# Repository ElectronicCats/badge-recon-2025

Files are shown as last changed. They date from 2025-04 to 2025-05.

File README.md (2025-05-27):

# REcon Badge 2025

This is the official repository of the REcon Badge 2025. Here you will find the source code for the badge, as well as the documentation and instructions to build it.

## Getting Started

Your badge comes with a pre-installed firmware, but in case you want to reprogram it, you can follow these steps:

1. Download the latest `firmware.uf2` file from the [releases](https://github.com/ElectronicCats/badge-recon-2025/releases/latest) page.

2. Connect the badge to your computer using a USB-C cable.

3. Press and hold the button on the badge while connecting it to the USB port. This will put the badge in bootloader mode.

4. Once the badge is connected, it will appear as a USB drive named `RPI-RP2`. Copy the `firmware.uf2` file to the root of the drive.

5. After copying the file, the badge will automatically reboot and start running the new firmware.

> **Note:** Sometimes you may need to press the reset button on the badge after copying the firmware file to ensure it starts correctly.

### Building the Firmware

To build the firmware from source, you will need to have [Docker](https://www.docker.com/) installed on your machine. Once you have Docker set up, you can follow these steps:

1. Clone the repository:

Using HTTPS:

```bash
git clone https://github.com/ElectronicCats/badge-recon-2025.git
```

Using SSH:

```bash
git clone git@github.com:ElectronicCats/badge-recon-2025.git
```

2. Navigate to the firmware directory:

```bash
cd badge-recon-2025/firmware
```

3. Build the firmware using Docker:

```bash
./build.sh
```

This script will create a `firmware.ino.uf2` file in the `firmware/build` directory.

> To flash the firmware to the badge, follow the same steps as mentioned in the "Getting Started" section, but use the newly built `firmware.ino.uf2` file instead of the pre-built one.

> If you find any issues, please open an issue on the GitHub repository.

## User guide

Your badge comes with an SSD1306 OLED display and 4 buttons for navigation. When you power on the badge, it will display a welcome screen and then show the main menu after you press any button.

All the available applications are listed in the following diagram:

```mermaid
flowchart TD
    Start([Power On]) --> Init[Initialize Hardware]
    Init --> Welcome[Welcome Screen]
    Welcome --> MainMenu[Main Menu]
    
    MainMenu --> Apps[Apps]
    MainMenu --> About[About Screen]
    
    Apps --> NFCMenu[NFC Menu]
    Apps --> MagspoofMenu[Magspoof Menu]
    
    %% NFC Menu items
    NFCMenu --> DetectTags[Detect Tags]
    NFCMenu --> DetectReaders[Detect Readers]
    NFCMenu --> ReadBlock[Read Block]
    NFCMenu --> WriteBlock[Write Block]
    
    %% Magspoof Menu items
    MagspoofMenu --> Emulate[Emulate]
    MagspoofMenu --> Setup[Setup]
    MagspoofMenu --> Help[Help]
    
    %% NFC operations
    DetectTags --> SetReaderMode[Set Reader Mode]
    SetReaderMode --> TagDetection{Tag Detected?}
    TagDetection -->|Yes| DisplayTagInfo[Display Tag Info]
    TagDetection -->|No| BackPressed{Back Pressed?}
    BackPressed -->|Yes| NFCMenu
    BackPressed -->|No| TagDetection
    DisplayTagInfo --> WaitForRemoval[Wait For Tag Removal]
    WaitForRemoval --> BackToMenu[Wait For Back Button]
    BackToMenu --> NFCMenu
    
    %% Magspoof operations
    Setup --> SerialPrompt[Serial Prompt for Tracks]
    SerialPrompt --> InputTracks[Input Track Data]
    InputTracks --> TracksUpdated[Tracks Updated]
    TracksUpdated --> MagspoofMenu
    
    %% Input controller
    subgraph InputControl [Input Controller]
        UpButton[Up Button]
        DownButton[Down Button]
        SelectButton[Select Button]
        BackButton[Back Button]
    end
    
    %% Easter egg
    UpButton --> KonamiCheck{Konami Code?}
    KonamiCheck -->|Yes| EasterEgg[Easter Egg hint]
    KonamiCheck -->|No| MainMenu
```

### NFC Applications

- **Read Block** and **Write Block** applications are the same as **Detect Tags**, but they perform read and read/write operations if the detected tag is a Mifare Classic tag.
- **Detect Readers** allows you to detect NFC readers by emulating a tag.

### Magspoof Application

The **Magspoof** application allows you to emulate a magnetic stripe card.

- You can set up the tracks by entering the data through the serial prompt, use 9600 baud rate to communicate with the badge.
- The **Emulate** option allows you to emulate the magnetic stripe card with the configured tracks.

### Easter Egg

You can get a hint about the Easter egg by pressing the Konami code while the badge shows the REcon logo. The Konami code is:

```
Up, Up, Down, Down, Left, Right, Left, Right
```

## License

<a href="https://github.com/ElectronicCats">
    
</a>

Electronic Cats invests time and resources providing this open source design, please support Electronic Cats and open-source hardware by purchasing products from Electronic Cats!

Designed by Electronic Cats.

Firmware released under an GNU AGPL v3.0 license. See the LICENSE file for more information.

Hardware released under an CERN Open Hardware Licence v1.2. See the LICENSE_HARDWARE file for more information.

Electronic Cats is a registered trademark, please do not use if you sell these PCBs.

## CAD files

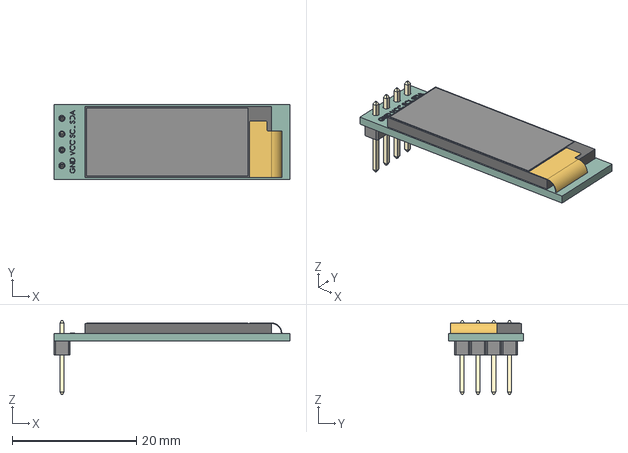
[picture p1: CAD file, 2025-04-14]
hardware/Footprints/3d/128x32-OLED.STEP
38.0 x 12.0 x 11.9 mm

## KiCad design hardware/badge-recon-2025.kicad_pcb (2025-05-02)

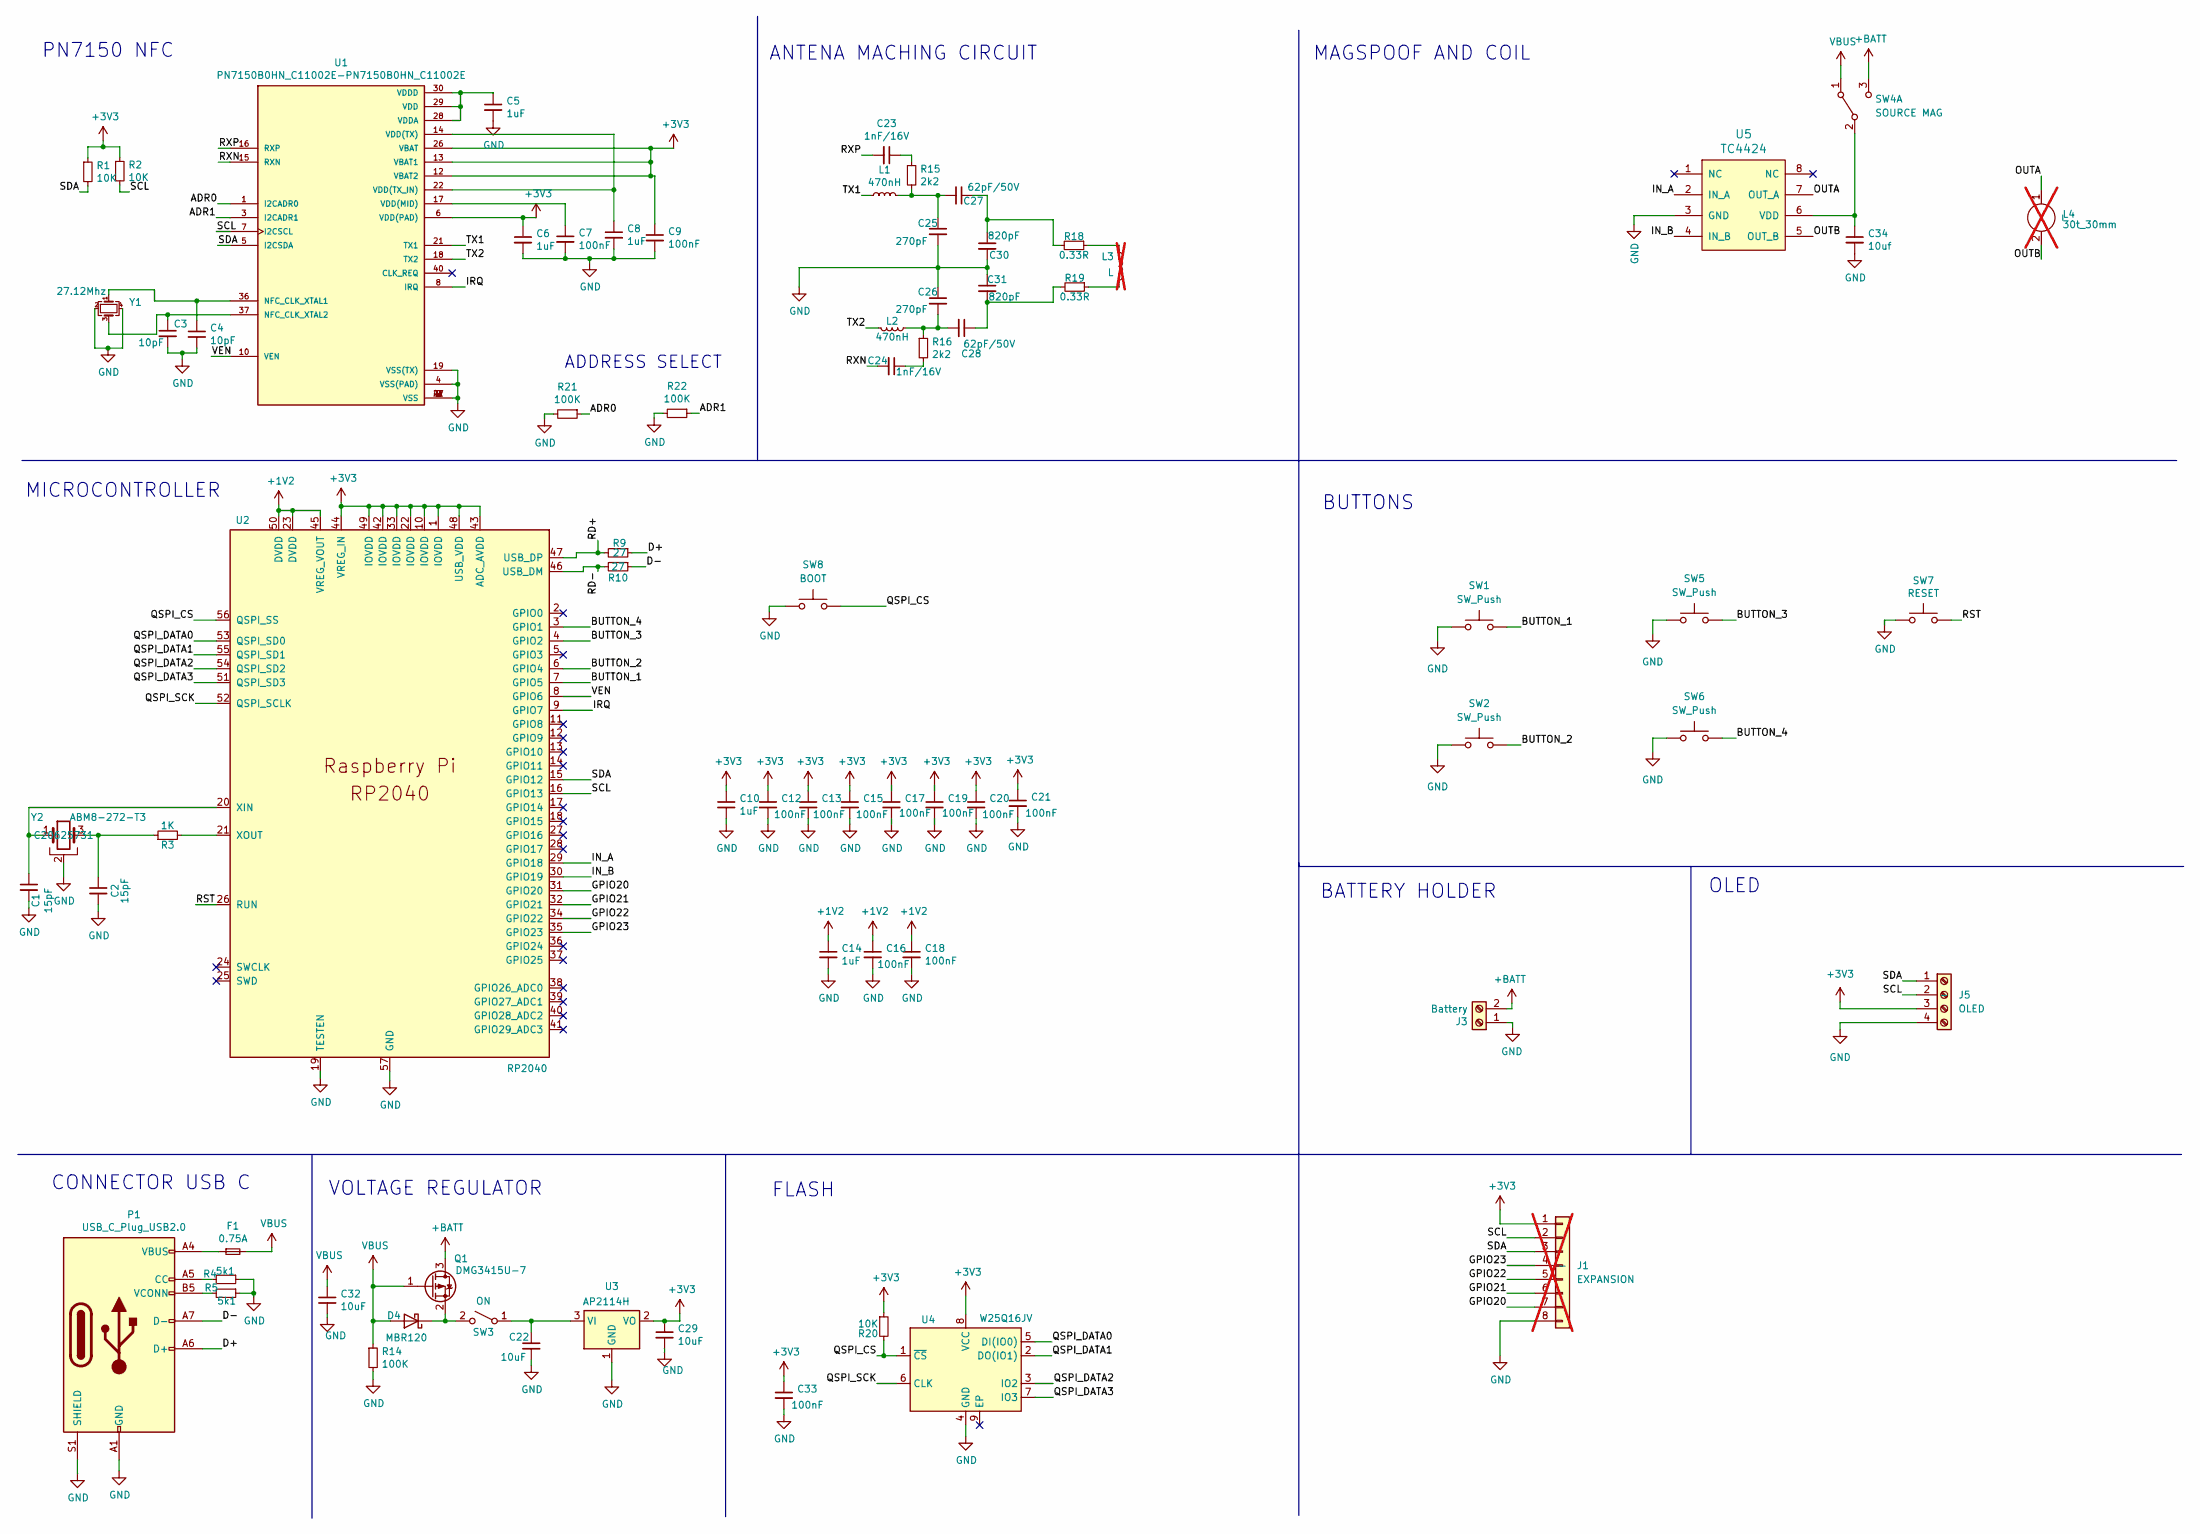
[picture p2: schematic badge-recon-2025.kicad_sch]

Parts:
C1, C2: 15pF; C_0603_1608Metric; LCSC# C1644
C3, C4: 10pF; C_0603_1608Metric; LCSC# C106245
C5, C6, C8, C10, C14: 1uF; C_0603_1608Metric; LCSC# C15849
C7, C9, C12, C13, C15, C16, C17, C18, C19, C20, C21, C33: 100nF; C_0603_1608Metric; LCSC# C282519
C22, C29, C32: 10uF; C_0603_1608Metric; LCSC# C85713
C23, C24: 1nF/16V; C_0603_1608Metric; LCSC# C519507
C25, C26: 270pF; C_0603_1608Metric; LCSC# C107046
C27, C28: 62pF/50V; C_0603_1608Metric; LCSC# C282073
C30, C31: 820pF; C_0603_1608Metric; LCSC# C107057
C34: 10uf; C_0603_1608Metric; LCSC# C96446
D4: MBR120; D_SOD-123F; LCSC# C130880
F1: 0.75A; Fuse_1812_4532Metric; LCSC# C3107
J1: EXPANSION; PinHeader_1x08_P2.54mm_Vertical; not fitted
J3: Battery; BAT-TH_BH-AAA-A1AJ024; LCSC# C5290193
J5: OLED; Display OLED 128 x32
L1, L2: 470nH; L_0603_1608Metric_Pad1.05x0.95mm_HandSolder; LCSC# C2044483
L3: L; NFC_Antenna_4T_Crossover_Final; not fitted
L4: 30t_30mm; Coil_30t_30mm_0.2_0.2_0.6_0.3; not fitted
P1: USB_C_Plug_USB2.0; C393939; LCSC# C393939
Q1: DMG3415U-7; SOT-23; LCSC# C96616
R1, R2, R20: 10K; R_0603_1608Metric; LCSC# C2930027
R3: 1K; R_0603_1608Metric; LCSC# C112433
R4, R5: 5k1; R_0603_1608Metric; LCSC# C23186
R9, R10: 27; R_0603_1608Metric; LCSC# C403464
R14, R21, R22: 100K; R_0603_1608Metric; LCSC# C15458
R15, R16: 2k2; R_0603_1608Metric; LCSC# C113303
R18, R19: 0.33R; R_0603_1608Metric; LCSC# C2934252
SW1, SW2, SW5, SW6: SW_Push; SW_SPST_TL3342; LCSC# C318889
SW3: ON; MSK12C02; LCSC# C431540
SW4: SOURCE MAG; JS202011CQN; LCSC# C5149820
SW7: RESET; SW_SPST_TL3342; LCSC# C318889
SW8: BOOT; SW_SPST_TL3342; LCSC# C318889
U1: PN7150B0HN_C11002E-PN7150B0HN_C11002E; QFN-40-1EP_6x6mm_P0.5mm_EP4.6x4.6mm; LCSC# C702907
U2: RP2040; RP2040-QFN-56; LCSC# C2040
U3: AP2114H; SOT-223-3_TabPin2; LCSC# C150716
U4: W25Q16JV; SOIC-8_5.3x5.3mm_P1.27mm; LCSC# C82317
U5: TC4424; SOIC-8_3.9x4.9mm_P1.27mm; LCSC# C7498963
Y1: 27.12Mhz; Crystal_SMD_2016-4Pin_2.0x1.6mm; LCSC# C338245
Y2: ABM8-272-T3; Crystal_SMD_Abracon_ABM8G-4Pin_3.2x2.5mm; LCSC# C20625731

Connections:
+1V2: C14.1, C16.1, C18.1, U2.23 (DVDD), U2.45 (VREG_VOUT), U2.50 (DVDD)
+3V3: C6.1, C9.1, C10.1, C12.1, C13.1, C15.1, C17.1, C19.1, C20.1, C21.1, C29.1, C33.1, J1.1, J5.3, R1.1, R2.1, R20.1, U1.6 (VDD(PAD)), U1.12 (VBAT2), U1.13 (VBAT1), U1.26 (VBAT), U2.1 (IOVDD), U2.10 (IOVDD), U2.22 (IOVDD), U2.33 (IOVDD), U2.42 (IOVDD), U2.43 (ADC_AVDD), U2.44 (VREG_IN), U2.48 (USB_VDD), U2.49 (IOVDD), U3.2 (VO), U4.8 (VCC)
+BATT: J3.2, Q1.3 (D), SW4.3 (C)
/ADR0: R21.1, U1.1 (I2CADR0)
/ADR1: R22.1, U1.3 (I2CADR1)
/BUTTON_1: SW1.2, U2.7 (GPIO5)
/BUTTON_2: SW2.2, U2.6 (GPIO4)
/BUTTON_3: SW5.2, U2.4 (GPIO2)
/BUTTON_4: SW6.2, U2.3 (GPIO1)
/D+: P1.A6 (D+), R9.1
/D-: P1.A7 (D-), R10.1
/GPIO20: J1.7, U2.31 (GPIO20)
/GPIO21: J1.6, U2.32 (GPIO21)
/GPIO22: J1.5, U2.34 (GPIO22)
/GPIO23: J1.4, U2.35 (GPIO23)
/IN_A: U2.29 (GPIO18), U5.2 (IN_A)
/IN_B: U2.30 (GPIO19), U5.4 (IN_B)
/IRQ: U1.8 (IRQ), U2.9 (GPIO7)
/OUTA: L4.1, U5.7 (OUT_A)
/OUTB: L4.2, U5.5 (OUT_B)
/QSPI_CS: R20.2, SW8.2, U2.56 (QSPI_SS), U4.1 (~CS)
/QSPI_DATA0: U2.53 (QSPI_SD0), U4.5 (DI(IO0))
/QSPI_DATA1: U2.55 (QSPI_SD1), U4.2 (DO(IO1))
/QSPI_DATA2: U2.54 (QSPI_SD2), U4.3 (IO2)
/QSPI_DATA3: U2.51 (QSPI_SD3), U4.7 (IO3)
/QSPI_SCK: U2.52 (QSPI_SCLK), U4.6 (CLK)
/RD+: R9.2, U2.47 (USB_DP)
/RD-: R10.2, U2.46 (USB_DM)
/RST: SW7.2, U2.26 (RUN)
/RXN: C24.2, U1.15 (RXN)
/RXP: C23.2, U1.16 (RXP)
/SCL: J1.2, J5.2, R2.2, U1.7 (I2CSCL), U2.16 (GPIO13)
/SDA: J1.3, J5.1, R1.2, U1.5 (I2CSDA), U2.15 (GPIO12)
/TX1: L1.1, U1.21 (TX1)
/TX2: L2.2, U1.18 (TX2)
/VEN: U1.10 (VEN), U2.8 (GPIO6)
GND: C1.2, C2.2, C3.2, C4.2, C5.2, C6.2, C7.2, C8.2, C9.2, C10.2, C12.2, C13.2, C14.2, C15.2, C16.2, C17.2, C18.2, C19.2, C20.2, C21.2, C22.2, C25.2, C26.1, C29.2, C30.2, C31.1, C32.2, C33.2, C34.2, J1.8, J3.1, J5.4, P1.A1 (GND), P1.A12 (GND), P1.B1 (GND), P1.B12 (GND), P1.S1 (SHIELD), R4.1, R5.1, R14.2, R21.2, R22.2, SW1.1, SW2.1, SW5.1, SW6.1, SW7.1, SW8.1, U1.2 (VSS), U1.4 (VSS(PAD)), U1.9 (VSS), U1.19 (VSS(TX)), U1.27 (VSS), U1.41 (VSS), U2.19 (TESTEN), U2.57 (GND), U3.1 (GND), U4.4 (GND), U5.3 (GND), Y1.2, Y1.4, Y2.2
unnamed: C2.1, R3.1, Y2.3
unnamed: C23.1, R15.1
unnamed: C24.1, R16.2
unnamed: C25.1, C27.2, L1.2, R15.2
unnamed: C26.2, C28.2, L2.1, R16.1
unnamed: C27.1, C30.1, R18.2
unnamed: C28.1, C31.2, R19.2
unnamed: D4.1 (K), Q1.2 (S), SW3.2 (B)
unnamed: F1.1, P1.A4 (VBUS), P1.A9 (VBUS), P1.B4 (VBUS), P1.B9 (VBUS)
unnamed: L3.1, R18.1
unnamed: L3.2, R19.1
unnamed: P1.A5 (CC), R4.2
unnamed: P1.B5 (VCONN), R5.2
unnamed: C22.1, SW3.1 (A), U3.3 (VI)
unnamed: C34.1, SW4.2 (B), U5.6 (VDD)
unnamed: C4.1, U1.36 (NFC_CLK_XTAL1), Y1.1
unnamed: C3.1, U1.37 (NFC_CLK_XTAL2), Y1.3
unnamed: C7.1, U1.17 (VDD(MID))
unnamed: C8.1, U1.14 (VDD(TX)), U1.22 (VDD(TX_IN))
unnamed: C5.1, U1.28 (VDDA), U1.29 (VDD), U1.30 (VDDD)
unnamed: C1.1, U2.20 (XIN), Y2.1
unnamed: R3.2, U2.21 (XOUT)
VBUS: C32.1, D4.2 (A), F1.2, Q1.1 (G), R14.1, SW4.1 (A)

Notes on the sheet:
ANTENA MACHING CIRCUIT
CONNECTOR USB C
PN7150 NFC
BATTERY HOLDER
BUTTONS
MAGSPOOF AND COIL
MICROCONTROLLER
VOLTAGE REGULATOR
FLASH
OLED
ADDRESS SELECT

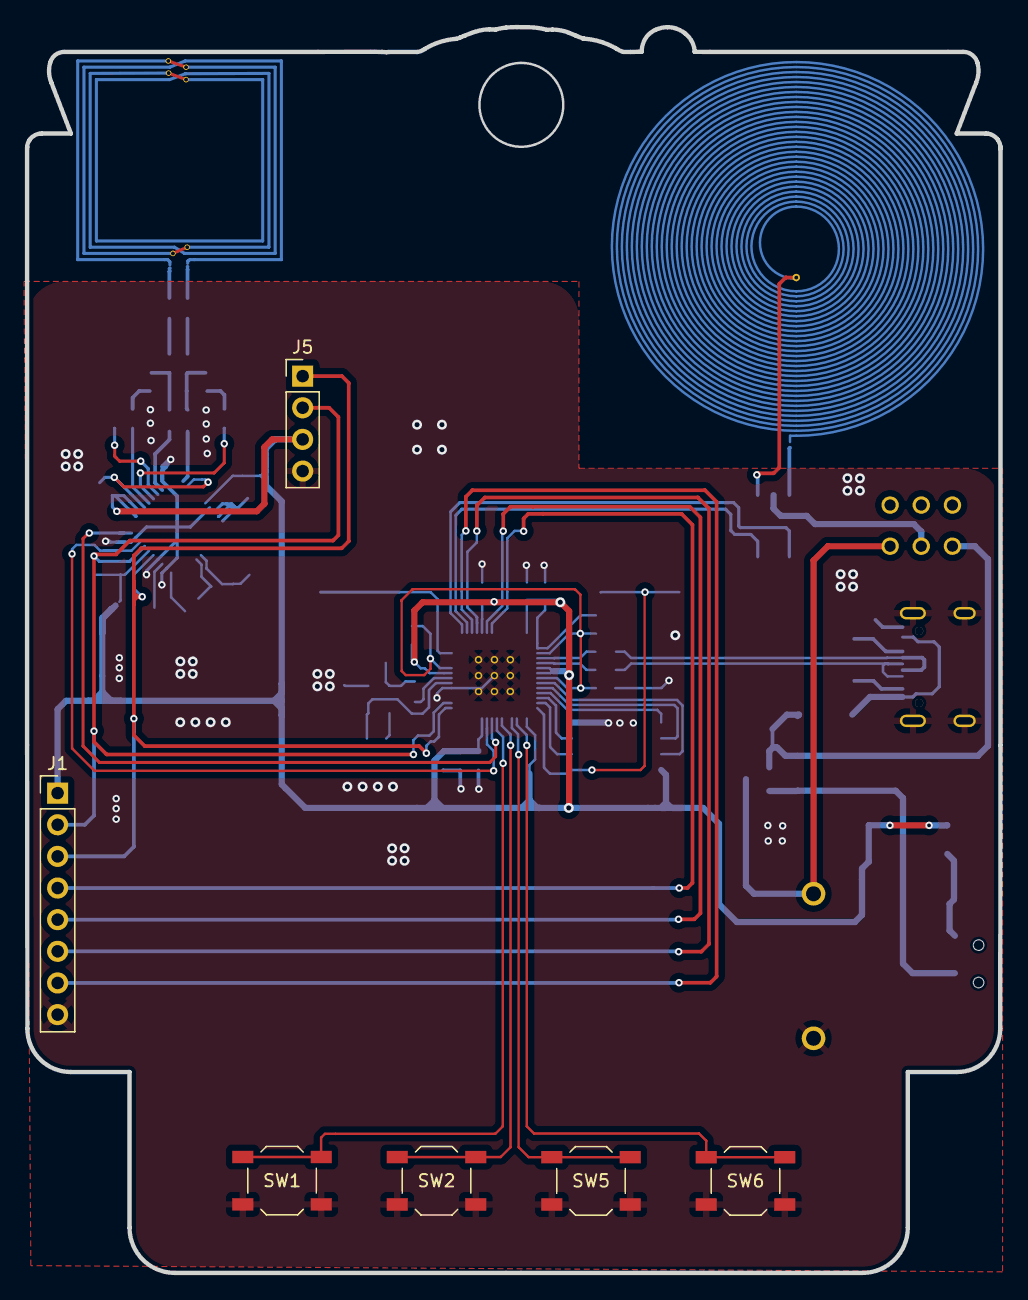
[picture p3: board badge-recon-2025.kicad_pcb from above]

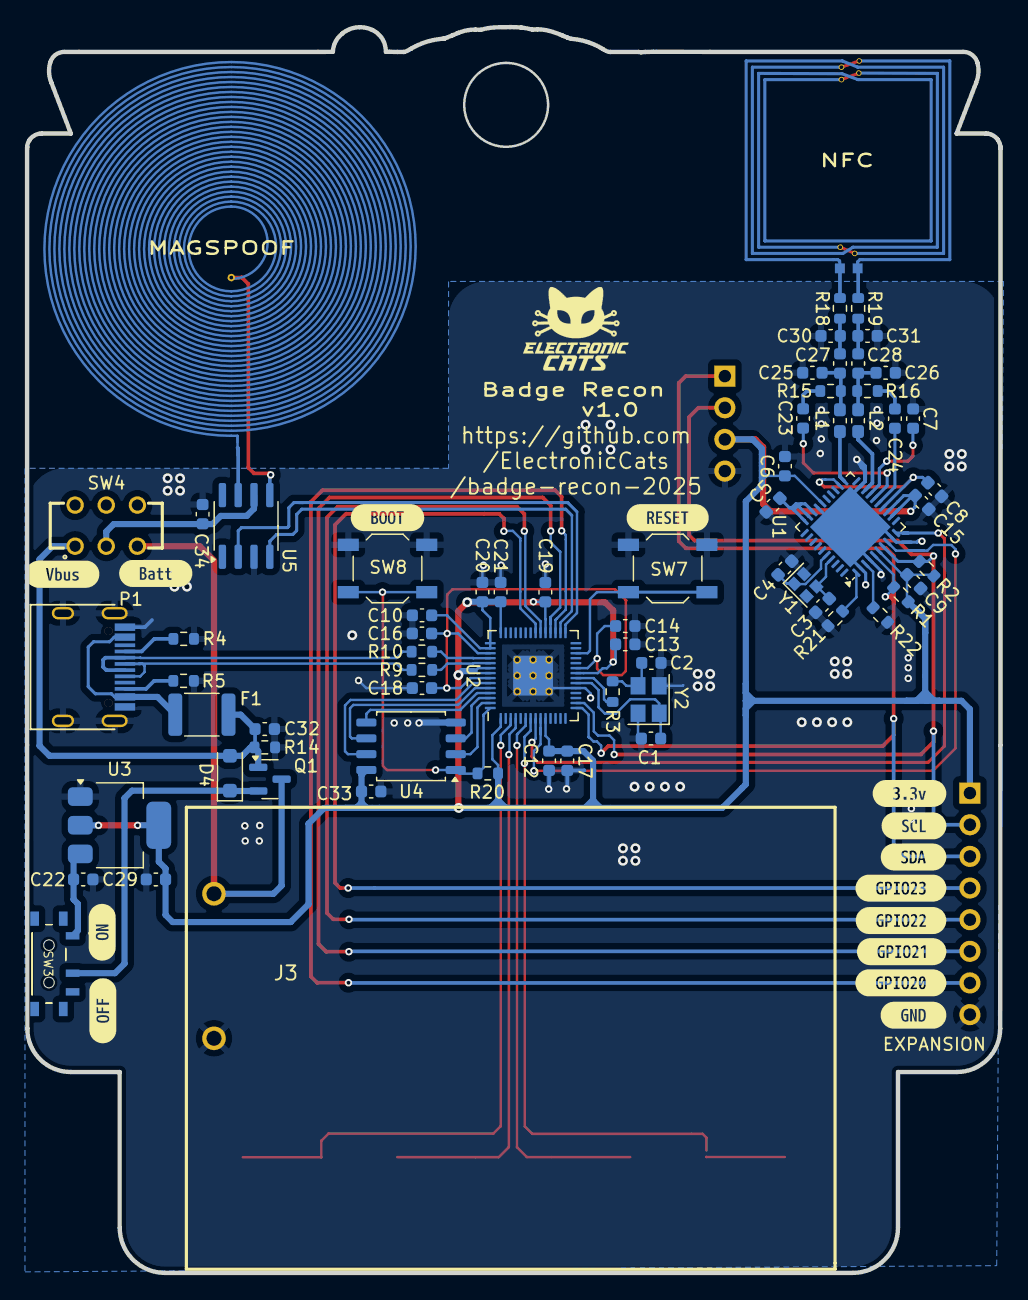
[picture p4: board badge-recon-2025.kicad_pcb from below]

Board: 2 copper layers, 78.1 x 100.0 mm, 88 parts (82 on the bottom side), 60 nets.

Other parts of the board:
kibuzzard-6806AEF7: G***; kibuzzard-6806AEF7
kibuzzard-6806AF2D: G***; kibuzzard-6806AF2D
kibuzzard-6806AF6E: G***; kibuzzard-6806AF6E
kibuzzard-6806AF7F: G***; kibuzzard-6806AF7F
kibuzzard-6806AF29: G***; kibuzzard-6806AF29
kibuzzard-6806AF43: G***; kibuzzard-6806AF43
kibuzzard-6806AF94: G***; kibuzzard-6806AF94
kibuzzard-6806AFC6: G***; kibuzzard-6806AFC6
kibuzzard-6806B2E8: G***; kibuzzard-6806B2E8
kibuzzard-6806B2F9: G***; kibuzzard-6806B2F9
kibuzzard-6814FFA5: G***; kibuzzard-6814FFA5
kibuzzard-6814FFAA: G***; kibuzzard-6814FFAA
kibuzzard-6815045B: G***; kibuzzard-6815045B
kibuzzard-68150444: G***; kibuzzard-68150444

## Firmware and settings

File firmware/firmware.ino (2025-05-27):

/**
 * @file badge-recon-2025.ino
 * @brief Main sketch for NFC tag detection system
 * @author Francisco Torres - Electronic Cats - electroniccats.com
 * @date May 2025
 *
 * This code is beerware; if you see me (or any other collaborator
 * member) at the local, and you've found our code helpful,
 * please buy us a round!
 * Distributed as-is; no warranty is given.
 */

#include <SPI.h>
#include <Wire.h>

#include <Adafruit_GFX.h>
#include <Adafruit_SSD1306.h>
#include <ezButton.h>
#include "Electroniccats_PN7150.h"

#include "display_controller.h"
#include "input_controller.h"
#include "magspoof.h"
#include "nfc_config.h"
#include "nfc_controller.h"
#include "nfc_display.h"

// Display configuration
#define SCREEN_WIDTH   128   // OLED display width in pixels
#define SCREEN_HEIGHT  32    // OLED display height in pixels
#define OLED_RESET     -1    // Reset pin (or -1 if sharing Arduino reset pin)
#define SCREEN_ADDRESS 0x3C  // I2C address of the SSD1306 display
#define IC2_SDA_PIN    12
#define IC2_SCL_PIN    13

// Buttons configuration
#define BUTTON_UP_PIN      5
#define BUTTON_DOWN_PIN    4
#define BUTTON_SELECT_PIN  2
#define BUTTON_BACK_PIN    1
#define BUTTON_DEBOUNCE_MS 50

// Menu system configuration
#define MAX_MENU_ITEMS 10  // Maximum items per menu level
#define DISPLAY_ROWS   3   // Maximum displayed items on screen

// Read/Write block configuration
// Block to be read
#define BLK_NB_MFC 4
// Default Mifare Classic key
#define KEY_MFC 0xFF, 0xFF, 0xFF, 0xFF, 0xFF, 0xFF

// Data to be written in the Mifare Classic block
#define DATA_WRITE_MFC                                                    \
  0x00, 0x11, 0x22, 0x33, 0x44, 0x55, 0x66, 0x77, 0x88, 0x99, 0xaa, 0xbb, \
      0xcc, 0xdd, 0xee, 0xff

/**
 * @brief Global NFC device interface object
 *
 * Creates a global NFC device interface object, attached to pins defined
 * in nfc_config.h and using the specified I2C address
 */
Electroniccats_PN7150 nfc(PN7150_IRQ, PN7150_VEN, PN7150_ADDR, PN7150, &Wire);

/**
 * @brief Display object for SSD1306 OLED
 */
Adafruit_SSD1306 display(SCREEN_WIDTH, SCREEN_HEIGHT, &Wire, OLED_RESET);

// Menu item type
typedef enum {
  MENU_TYPE_SUBMENU,  // Has submenu
  MENU_TYPE_FUNCTION  // Runs a function
} MenuItemType;

// Forward declarations of menu action functions
void runDetectTags();
void runDetectReaders();
void runReadBlock();
void runWriteBlock();
void runMagspoof();
void runMagspoofSetup();
void setupTracks(String newTrack1 = "", String newTrack2 = "");
void showAbout();
void showMagspoofHelp();

// Menu item structure
typedef struct {
  const char* name;   // Display name
  MenuItemType type;  // Type of menu item
  union {
    uint8_t submenuId;   // ID of submenu if type is MENU_TYPE_SUBMENU
    void (*function)();  // Function to call if type is MENU_TYPE_FUNCTION
  };
} MenuItem;

// Menu structure
typedef struct {
  const char* name;                // Menu name
  uint8_t itemCount;               // Number of items
  MenuItem items[MAX_MENU_ITEMS];  // Menu items
} Menu;

// Menu definitions
enum { MENU_MAIN = 0, MENU_APPS, MENU_NFC, MENU_MAGSPOOF, MENU_COUNT };

/**
 * @brief Menu controller class
 *
 * Handles menu navigation, rendering, and user interaction
 */
class MenuController {
 public:
  /**
   * @brief Initialize the menu system
   */
  void initialize();

  /**
   * @brief Update menu state based on inputs
   * Should be called in main loop
   */
  void update();

  /**
   * @brief Render current menu to display
   */
  void render();

 private:
  uint8_t _currentMenuId;    // Current menu level
  uint8_t _currentIndex;     // Currently selected item
  uint8_t _scrollOffset;     // Scroll offset for displaying items
  uint8_t _menuStackIds[5];  // Menu navigation history
  uint8_t _menuStackPos;     // Position in menu history

  // Navigation functions
  void navigateUp();
  void navigateDown();
  void navigateSelect();
  void navigateBack();

  // Helper functions
  void adjustScroll();
};

// Define menus
Menu menus[MENU_COUNT] = {
    // Main Menu
    {"Main Menu",
     2,
     {{"Apps", MENU_TYPE_SUBMENU, {.submenuId = MENU_APPS}},
      {"About", MENU_TYPE_FUNCTION, {.function = showAbout}}}},

    // Apps Menu
    {"Apps",
     2,
     {{"NFC", MENU_TYPE_SUBMENU, {.submenuId = MENU_NFC}},
      {"Magspoof", MENU_TYPE_SUBMENU, {.submenuId = MENU_MAGSPOOF}}}},

    // NFC Menu
    {"NFC",
     4,
     {{"Detect Tags", MENU_TYPE_FUNCTION, {.function = runDetectTags}},
      {"Detect Readers", MENU_TYPE_FUNCTION, {.function = runDetectReaders}},
      {"Read block", MENU_TYPE_FUNCTION, {.function = runReadBlock}},
      {"Write block", MENU_TYPE_FUNCTION, {.function = runWriteBlock}}}},

    // Magspoof Menu
    {"Magspoof",
     3,
     {{"Emulate", MENU_TYPE_FUNCTION, {.function = runMagspoof}},
      {"Setup", MENU_TYPE_FUNCTION, {.function = runMagspoofSetup}},
      {"Help", MENU_TYPE_FUNCTION, {.function = showMagspoofHelp}}}}};

MenuController menuController;

// MenuController implementation
void MenuController::initialize() {
  _currentMenuId = MENU_MAIN;
  _currentIndex = 0;
  _scrollOffset = 0;
  _menuStackPos = 0;

  // Reset menu navigation stack
  memset(_menuStackIds, 0, sizeof(_menuStackIds));
}

void MenuController::update() {
  inputController.update();

  if (inputController.isUpPressed()) {
    navigateUp();
  } else if (inputController.isDownPressed()) {
    navigateDown();
  } else if (inputController.isSelectPressed()) {
    navigateSelect();
  } else if (inputController.isBackPressed()) {
    navigateBack();
  }
}

void MenuController::render() {
  Adafruit_SSD1306* display = displayController.getDisplay();
  Menu* currentMenu = &menus[_currentMenuId];

  display->clearDisplay();

  // Draw title
  display->setTextSize(1);
  display->setTextColor(SSD1306_WHITE);
  display->setCursor(0, 0);
  display->println(currentMenu->name);

  // Draw separator line
  display->drawLine(0, 8, display->width(), 8, SSD1306_WHITE);

  // Draw menu items
  for (uint8_t i = 0;
       i < DISPLAY_ROWS && i + _scrollOffset < currentMenu->itemCount; i++) {
    uint8_t yPos = 10 + i * 8;

    // Highlight selected item
    if (i + _scrollOffset == _currentIndex) {
      display->fillRect(0, yPos - 1, display->width(), 8, SSD1306_WHITE);
      display->setTextColor(SSD1306_BLACK);
    } else {
      display->setTextColor(SSD1306_WHITE);
    }

    display->setCursor(2, yPos);
    display->println(currentMenu->items[i + _scrollOffset].name);

    // Draw submenu indicator
    if (currentMenu->items[i + _scrollOffset].type == MENU_TYPE_SUBMENU) {
      display->setCursor(display->width() - 6, yPos);
      display->print(">");
    }
  }

  // Draw scroll indicators if necessary
  if (_scrollOffset > 0) {
    display->fillTriangle(display->width() - 5, 9, display->width() - 8, 12,
                          display->width() - 2, 12, SSD1306_WHITE);
  }

  if (_scrollOffset + DISPLAY_ROWS < currentMenu->itemCount) {
    display->fillTriangle(display->width() - 5, 31, display->width() - 8, 28,
                          display->width() - 2, 28, SSD1306_WHITE);
  }

  display->display();
}

void MenuController::navigateUp() {
  if (_currentIndex > 0) {
    _currentIndex--;
    adjustScroll();
  }
}

void MenuController::navigateDown() {
  if (_currentIndex < menus[_currentMenuId].itemCount - 1) {
    _currentIndex++;
    adjustScroll();
  }
}

void MenuController::navigateSelect() {
  Menu* currentMenu = &menus[_currentMenuId];
  MenuItem* selectedItem = &currentMenu->items[_currentIndex];

  if (selectedItem->type == MENU_TYPE_SUBMENU) {
    // Push current menu to stack
    _menuStackIds[_menuStackPos++] = _currentMenuId;

    // Navigate to submenu
    _currentMenuId = selectedItem->submenuId;
    _currentIndex = 0;
    _scrollOffset = 0;
  } else if (selectedItem->type == MENU_TYPE_FUNCTION) {
    selectedItem->function();
  }
}

void MenuController::navigateBack() {
  if (_menuStackPos > 0) {
    // Pop menu from stack
    _currentMenuId = _menuStackIds[--_menuStackPos];
    _currentIndex = 0;
    _scrollOffset = 0;
  }
}

void MenuController::adjustScroll() {
  if (_currentIndex < _scrollOffset) {
    _scrollOffset = _currentIndex;
  } else if (_currentIndex >= _scrollOffset + DISPLAY_ROWS) {
    _scrollOffset = _currentIndex - DISPLAY_ROWS + 1;
  }
}

void runDetectTags() {
  Adafruit_SSD1306* display = displayController.getDisplay();
  display->clearDisplay();
  display->setTextColor(SSD1306_WHITE);
  display->setCursor(0, 0);
  display->println(F("Detecting tags..."));
  display->println(F("Place tag near"));
  display->println(F("the antenna"));
  display->display();

  // Set card reader/writer mode - required for tag detection
  nfc.setReaderWriterMode();

  bool tagDetected = false;
  String tagInfo;
  while (!inputController.isBackPressed()) {
    inputController.update();
    if (nfc.isTagDetected()) {
      tagDetected = true;
      tagInfo = getTagInfoForDisplay(nfc);

      display->clearDisplay();
      display->setCursor(0, 0);
      display->println(F("Tag detected!"));
      display->println(F("Please remove it"));
      display->println(F("from the antenna"));
      display->display();

      // It can detect multiple cards at the same time if they use the same
      // protocol
      if (nfc.remoteDevice.hasMoreTags()) {
        nfc.activateNextTagDiscovery();
      }

      nfc.waitForTagRemoval();
    }

    nfc.reset();

    if (tagDetected) {
      break;
    }

    delay(10);
  }

  if (tagDetected) {
    // Add instructions to the tag info
    tagInfo += "\n\nPress BACK button";

    displayController.showTagInfo(tagInfo);

    // Wait for back button instead of using a fixed delay
    while (!inputController.isBackPressed()) {
      inputController.update();
      delay(10);
    }
  } else {
    display->clearDisplay();
    display->setTextColor(SSD1306_WHITE);
    display->setCursor(0, 0);
    display->println(F("No tag detected"));
    display->println(F("Press BACK to"));
    display->println(F("return to menu"));
    display->display();
  }

  nfc.reset();

  // Wait for back button press to return to menu
  while (!inputController.isBackPressed()) {
    inputController.update();
    delay(10);
  }
}

void runDetectReaders() {
  Adafruit_SSD1306* display = displayController.getDisplay();
  display->clearDisplay();
  display->setTextColor(SSD1306_WHITE);
  display->setCursor(0, 0);
  display->println(F("Detect Readers"));
  display->println(F("Please wait..."));
  display->display();

  while (!initializeNfcController(nfc)) {
    delay(1000);
  }

  // Set card emulation mode - required for reader detection
  nfc.setEmulationMode();

  display->clearDisplay();
  display->setCursor(0, 0);
  display->println(F("Waiting for reader"));
  display->println(F("Hold near a phone"));
  display->println(F("or card reader"));
  display->println(F("BACK to cancel"));
  display->display();

  // Animation dots for waiting
  uint8_t animDots = 0;
  uint8_t animFrame = 0;
  unsigned long lastAnimUpdate = 0;
  boolean readerFound = false;

  // Wait for reader detection or back button
  while (!inputController.isBackPressed()) {
    inputController.update();

    if (nfc.isReaderDetected()) {
      readerFound = true;
      nfc.handleCardEmulation();
      nfc.closeCommunication();
      break;
    }
  }

  if (readerFound) {
    display->clearDisplay();
    display->setCursor(0, 0);
    display->println(F("Reader detected!"));
    display->println(F("Emulation complete"));
    display->println(F("Press BACK button"));
    display->display();

    // Wait for back button to return to menu
    while (!inputController.isBackPressed()) {
      inputController.update();
      delay(10);
    }
  }

  nfc.reset();
}

bool mifare_read_block(void) {
  Adafruit_SSD1306* display = displayController.getDisplay();
  display->setTextColor(SSD1306_WHITE);

  bool status;
  unsigned char Resp[256];
  unsigned char RespSize;
  /* Authenticate sector 1 with generic keys */
  unsigned char Auth[] = {0x40, BLK_NB_MFC / 4, 0x10, KEY_MFC};
  /* Read block 4 */
  unsigned char Read[] = {0x10, 0x30, BLK_NB_MFC};

  /* Authenticate */
  status = nfc.readerTagCmd(Auth, sizeof(Auth), Resp, &RespSize);
  if ((status == NFC_ERROR) || (Resp[RespSize - 1] != 0)) {
    display->clearDisplay();
    display->setCursor(0, 0);
    display->println(F("Auth error!"));
    display->display();
    return false;
  }

  /* Read block */
  status = nfc.readerTagCmd(Read, sizeof(Read), Resp, &RespSize);
  if ((status == NFC_ERROR) || (Resp[RespSize - 1] != 0)) {
    display->clearDisplay();
    display->setCursor(0, 0);
    display->println(F("Error reading sector!"));
    display->display();
    return false;
  }

  return true;
}

bool mifare_read_write_block(void) {
  Adafruit_SSD1306* display = displayController.getDisplay();
  display->setTextColor(SSD1306_WHITE);

  bool status;
  unsigned char Resp[256];
  unsigned char RespSize;
  /* Authenticate sector 1 with generic keys */
  unsigned char Auth[] = {0x40, BLK_NB_MFC / 4, 0x10, KEY_MFC};
  /* Read block 4 */
  unsigned char Read[] = {0x10, 0x30, BLK_NB_MFC};
  /* Write block 4 */
  unsigned char WritePart1[] = {0x10, 0xA0, BLK_NB_MFC};
  unsigned char WritePart2[] = {0x10, DATA_WRITE_MFC};

  // Determine ChipWriteAck based on chip model
  uint8_t ChipWriteAck = (nfc.getChipModel() == PN7160) ? 0x14 : 0x00;

  /* Authenticate */
  status = nfc.readerTagCmd(Auth, sizeof(Auth), Resp, &RespSize);
  if ((status == NFC_ERROR) || (Resp[RespSize - 1] != 0)) {
    display->clearDisplay();
    display->setCursor(0, 0);
    display->println(F("Auth error!"));
    display->display();
    return false;
  }

  /* Read block */
  status = nfc.readerTagCmd(Read, sizeof(Read), Resp, &RespSize);
  if ((status == NFC_ERROR) || (Resp[RespSize - 1] != 0)) {
    display->clearDisplay();
    display->setCursor(0, 0);
    display->println(F("Error reading sector!"));
    display->display();
    return false;
  }

  /* Write block */
  status = nfc.readerTagCmd(WritePart1, sizeof(WritePart1), Resp, &RespSize);
  if ((status == NFC_ERROR) || (Resp[RespSize - 1] != ChipWriteAck)) {
    display->clearDisplay();
    display->setCursor(0, 0);
    display->println(F("Error writing block!"));
    display->display();
    return false;
  }

  status = nfc.readerTagCmd(WritePart2, sizeof(WritePart2), Resp, &RespSize);
  if ((status == NFC_ERROR) || (Resp[RespSize - 1] != ChipWriteAck)) {
    display->clearDisplay();
    display->setCursor(0, 0);
    display->println(F("Error writing block!"));
    display->display();
    return false;
  }

  /* Read block again to see te changes*/
  status = nfc.readerTagCmd(Read, sizeof(Read), Resp, &RespSize);
  if ((status == NFC_ERROR) || (Resp[RespSize - 1] != 0)) {
    display->clearDisplay();
    display->setCursor(0, 0);
    display->println(F("Error reading block!"));
    display->println(F("After writing"));
    display->display();
    return false;
  }

  return true;
}

void runReadBlock() {
  Adafruit_SSD1306* display = displayController.getDisplay();
  display->clearDisplay();
  display->setTextColor(SSD1306_WHITE);
  display->setCursor(0, 0);
  display->println(F("Detecting tags..."));
  display->println(F("Place tag near"));
  display->println(F("the antenna"));
  display->display();

  // Set card reader/writer mode - required for tag detection
  nfc.setReaderWriterMode();

  bool tagDetected = false;
  while (!inputController.isBackPressed()) {
    inputController.update();

    if (nfc.isTagDetected()) {
      tagDetected = true;

      display->clearDisplay();
      display->setCursor(0, 0);
      display->println(F("Tag detected!"));

      switch (nfc.remoteDevice.getProtocol()) {
        case nfc.protocol.MIFARE:
          display->println(F("Starting reading"));
          display->println(F("process..."));
          display->display();
          if (mifare_read_block()) {
            display->clearDisplay();
            display->setCursor(0, 0);
            display->println(F("Successful read!"));
            display->display();
          }
          break;

        default:
          display->println(F("but it is not Mifare"));
          display->display();
          break;
      }

      // It can detect multiple cards at the same time if they use the same
      // protocol
      if (nfc.remoteDevice.hasMoreTags()) {
        nfc.activateNextTagDiscovery();
      }

      display->println(F("Please remove the tag"));
      display->println(F("from the antenna"));
      display->display();

      nfc.waitForTagRemoval();
    }

    nfc.reset();
    delay(10);

    if (tagDetected) {
      break;
    }
  }

  if (tagDetected) {
    display->println(F("Press BACK button"));
    display->display();

    while (!inputController.isBackPressed()) {
      inputController.update();
      delay(10);
    }
  } else {
    display->clearDisplay();
    display->setTextColor(SSD1306_WHITE);
    display->setCursor(0, 0);
    display->println(F("No tag detected"));
    display->println(F("Press BACK to"));
    display->println(F("return to menu"));
    display->display();
  }

  nfc.reset();

  while (!inputController.isBackPressed()) {
    inputController.update();
    delay(10);
  }
}

void runWriteBlock() {
  Adafruit_SSD1306* display = displayController.getDisplay();
  display->clearDisplay();
  display->setTextColor(SSD1306_WHITE);
  display->setCursor(0, 0);
  display->println(F("Detecting tags..."));
  display->println(F("Place tag near"));
  display->println(F("the antenna"));
  display->display();

  // Set card reader/writer mode - required for tag detection
  nfc.setReaderWriterMode();

  bool tagDetected = false;
  while (!inputController.isBackPressed()) {
    inputController.update();

    if (nfc.isTagDetected()) {
      tagDetected = true;

      display->clearDisplay();
      display->setCursor(0, 0);
      display->println(F("Tag detected!"));

      switch (nfc.remoteDevice.getProtocol()) {
        case nfc.protocol.MIFARE:
          display->println(F("Starting writing"));
          display->println(F("process..."));
          display->display();
          if (mifare_read_write_block()) {
            display->clearDisplay();
            display->setCursor(0, 0);
            display->println(F("Successful write!"));
            display->display();
          }
          break;

        default:
          display->println(F("but it is not Mifare"));
          display->display();
          break;
      }

      // It can detect multiple cards at the same time if they use the same
      // protocol
      if (nfc.remoteDevice.hasMoreTags()) {
        nfc.activateNextTagDiscovery();
      }

      display->println(F("Please remove the tag"));
      display->println(F("from the antenna"));
      display->display();

      nfc.waitForTagRemoval();
    }

    nfc.reset();
    delay(10);

    if (tagDetected) {
      break;
    }
  }

  if (tagDetected) {
    display->println(F("Press BACK button"));
    display->display();

    while (!inputController.isBackPressed()) {
      inputController.update();
      delay(10);
    }
  } else {
    display->clearDisplay();
    display->setTextColor(SSD1306_WHITE);
    display->setCursor(0, 0);
    display->println(F("No tag detected"));
    display->println(F("Press BACK to"));
    display->println(F("return to menu"));
    display->display();
  }

  nfc.reset();

  while (!inputController.isBackPressed()) {
    inputController.update();
    delay(10);
  }
}

void runMagspoofSetup() {
  Adafruit_SSD1306* display = displayController.getDisplay();
  display->clearDisplay();
  display->setTextColor(SSD1306_WHITE);
  display->setCursor(0, 0);
  display->println(F("Connect to a PC"));
  display->println(F("to update the tracks"));
  display->println(F("Press BACK to"));
  display->println(F("return to menu"));
  display->display();

  enum SetupState { WAITING_TRACK1, WAITING_TRACK2, SETUP_COMPLETE };

  SetupState currentState = WAITING_TRACK1;
  String track1 = "";
  String track2 = "";

  // Time tracking for periodic serial messages
  unsigned long lastSerialPrompt = 0;
  const unsigned long serialPromptInterval = 5000;  // 5 seconds

  // Send initial prompt
  Serial.println("Insert track 1:");
  lastSerialPrompt = millis();

  while (!inputController.isBackPressed()) {
    inputController.update();

    if (currentState != SETUP_COMPLETE) {
      unsigned long currentTime = millis();
      if (currentTime - lastSerialPrompt >= serialPromptInterval) {
        if (currentState == WAITING_TRACK1) {
          Serial.println("Insert track 1:");
        } else if (currentState == WAITING_TRACK2) {
          Serial.println("Insert track 2:");
        }
        lastSerialPrompt = currentTime;
      }

      if (Serial.available() > 0) {
        String input = Serial.readStringUntil('\n');
        input.trim();  // Remove any whitespace

        if (input.length() > 0) {
          if (currentState == WAITING_TRACK1) {
            // Save track 1 and move to track 2
            track1 = input;
            Serial.println("Track 1 received: " + track1);
            Serial.println("Insert track 2:");
            currentState = WAITING_TRACK2;
            lastSerialPrompt = millis();
          } else if (currentState == WAITING_TRACK2) {
            // Save track 2 and complete setup
            track2 = input;
            Serial.println("Track 2 received: " + track2);

            setupTracks(track1, track2);

            display->clearDisplay();
            display->setCursor(0, 0);
            display->println(F("Tracks updated!"));
            display->println(F("Press BACK to return"));
            display->display();

            currentState = SETUP_COMPLETE;
          }
        }
      }
    }

    delay(10);
  }
}
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
void loop() {
  menuController.update();  // Update menu state based on button inputs
  menuController.render();
  delay(10);
}

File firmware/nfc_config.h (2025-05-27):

/**
 * @file nfc_config.h
 * @brief Configuration constants for the NFC reader
 * @author Francisco Torres - Electronic Cats - electroniccats.com
 * @date May 2025
 *
 * This file contains all hardware-specific configuration parameters
 * for the NFC reader.
 */

#ifndef NFC_CONFIG_H
#define NFC_CONFIG_H

/**
 * @brief PIN definitions for PN7150/PN7160
 */
#define PN7150_IRQ  (7)    ///< IRQ pin connection
#define PN7150_VEN  (6)    ///< VEN pin connection
#define PN7150_ADDR (0x28)  ///< I2C address of the device

/**
 * @brief Serial monitor configuration
 */
#define SERIAL_BAUD_RATE (9600)  ///< Baud rate for serial communication

/**
 * @brief Timing configurations
 */
#define DETECTION_DELAY_MS (500)  ///< Delay between detection attempts

#endif  // NFC_CONFIG_H

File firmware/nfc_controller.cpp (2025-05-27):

/**
 * @file nfc_controller.cpp
 * @brief Implementation of NFC controller management functions
 * @author Francisco Torres - Electronic Cats - electroniccats.com
 * @date May 2025
 */

#include "nfc_controller.h"
#include "nfc_config.h"
#include "nfc_display.h"

bool initializeNfcController(Electroniccats_PN7150& nfc) {
  Serial.println("Initializing...");

  // Wake up the NFC board
  if (nfc.connectNCI()) {
    Serial.println("Error while setting up the mode, check connections!");
    return false;
  }

  // Configure NFC settings
  if (nfc.configureSettings()) {
    Serial.println("The Configure Settings has failed!");
    return false;
  }

  // Set Read/Write mode as default
  if (nfc.configMode()) {
    Serial.println("The Configure Mode has failed!!");
    return false;
  }

  // Start NCI Discovery mode
  nfc.startDiscovery();
  return true;
}

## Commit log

2025-04-07 feat(hw): add kicad project & add components in schematic
    [badge-recon-2025.kicad_pcb, badge-recon-2025.kicad_sch]
2025-04-07 feat(hw): add oled in schematic
    [badge-recon-2025.kicad_sch]
2025-04-16 feat(Hw): add antenna missing matching circuit
    [badge-recon-2025.kicad_pcb, badge-recon-2025.kicad_sch]
2025-04-16 feat(Hw): add ideal matching circuit
    [badge-recon-2025.kicad_pcb, badge-recon-2025.kicad_sch]
2025-04-18 Feat(Hw): floorplan added
    [badge-recon-2025.kicad_pcb, badge-recon-2025.kicad_sch]
2025-04-20 feat(Hw): update part numbers for JLCPCB assembly
    [badge-recon-2025.kicad_pcb, badge-recon-2025.kicad_sch]
2025-04-22 feat(Hw): add expansor, 0 unconnected, missing pn7150 crystal
    [badge-recon-2025.kicad_pcb, badge-recon-2025.kicad_sch]
2025-04-23 feat(Hw): update part numbers for jlcpcb
    [badge-recon-2025.kicad_sch]
2025-04-23 fix(Hw): set component as dnp & move routes
    [badge-recon-2025.kicad_pcb, badge-recon-2025.kicad_sch]
2025-04-23 fix(Hw): fix traces
    [badge-recon-2025.kicad_pcb]
2025-05-07 fix: ic2 and pn7150 pins
    [firmware.ino, nfc_config.h, nfc_controller.cpp]
2025-05-11 feat: add buttons integration
2025-05-19 fix: detect tags do not work
    [firmware.ino]
2025-05-23 feat: show logo until user presses a any button
2025-05-23 feat: add reboot counter
    [firmware.ino]
2025-05-26 feat: remove set chip warning
    - Remove useless comments
    - Remove useless prints
2025-05-26 fix: write block validation statements
    [firmware.ino]
